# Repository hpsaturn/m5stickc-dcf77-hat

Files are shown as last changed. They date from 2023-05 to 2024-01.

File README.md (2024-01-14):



# M5StickC DCF77 HAT

Basic hat implementation of a DCF77 receiver on a M5StickC-Plus or compatible ESP32 devices. This firmware uses an [improvement of Arduino-DCF77 library](https://github.com/hpsaturn/Arduino-DCF77), using an event callback to improve the GUI and signal representation.

<table>
	<tr>
		<td>
			Don't forget to star ⭐ this repository
		</td>
	</tr>
</table>

## Device

The current firmware was tested on 77.5KHZ single frequency device. It is the 4 pins version and it was bought in [Aliexpress](https://www.aliexpress.com/item/1005005254051736.html).

## Wiring

| M5StickC pin | DCF77 pin | Description |
|:----:|:----:|:---|
| 0 | P | PON: Enable/Disable |
| 26 | T | Interrupt pin or data |
| 3.3v | VDD | Positive (3.3v) |
| GND  | GND | Ground / unlabeled pin |

(see the photos in [Thingiverse](https://www.thingiverse.com/thing:6033436))

## Usage

**Some tips:**  

- [x] Check the right device. Some devices has different frequencies for each country.
- [x] Try to leave the device from away any radio or wireless interference or noise. The radio is very susceptible to noise.
- [x] In indoors it works, but is possible that in some builds doesn't. Try in outdoors first.
- [x] The position of the device for me was important, in horizontal is possible that it works better

**Buttons:**

- Left button: Power ON/Off
- M5 Button: Backlight or brightness toggle
- Right button: Unimplementened  

## Installation

Please install first [PlatformIO](http://platformio.org/) open source ecosystem for IoT development compatible with **Arduino** IDE and its command line tools (Windows, MacOs and Linux). Also, you may need to install [git](http://git-scm.com/) in your system.

For the **default** board, the `M5StickCPlus`, only clone this and upload firmware via USB cable with a simple command:

`pio run --target upload`

or import the project in VSCode and build and run it.

## Box

Is a basic box - hat for these devices, for example M5StickC or M5StickC-Plus, also should be work in M5CoreInk device.

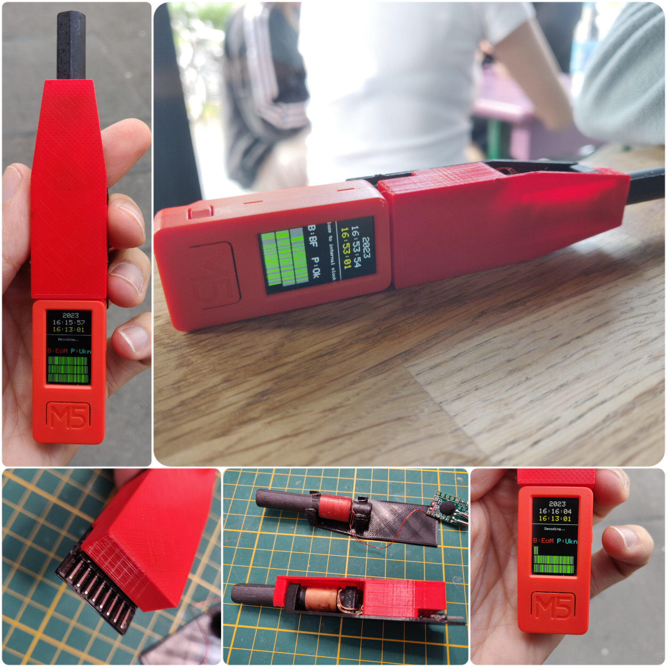
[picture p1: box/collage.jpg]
Box DCF77 M5StickCPlus Hat (https://youtu.be/C50qMhYiE60)


**Files:**  

DCF77 box base  
DCF77 box lid  

Also in [Thingiverse](https://www.thingiverse.com/thing:6033436).  

---

## Thanks to

@felmue to fix a sporadical crash.  
@jcomas for the help and docs on https://t.me/esp_es  
The old [DCF77 library](https://github.com/thijse/Arduino-DCF77)  
The [Seiko documentation](https://www.seikowatches.com/instructions/html/SEIKO_8B92_EN/CWVVSYxxhbpilh)

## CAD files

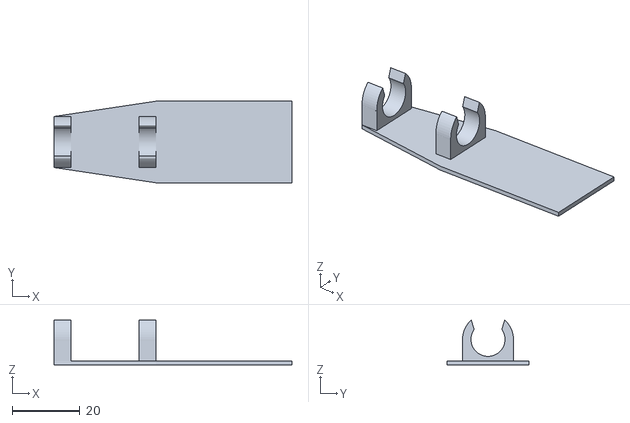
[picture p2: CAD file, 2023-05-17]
box/dfc77_holder_vertical.stl
70.0 x 24.0 x 13.2

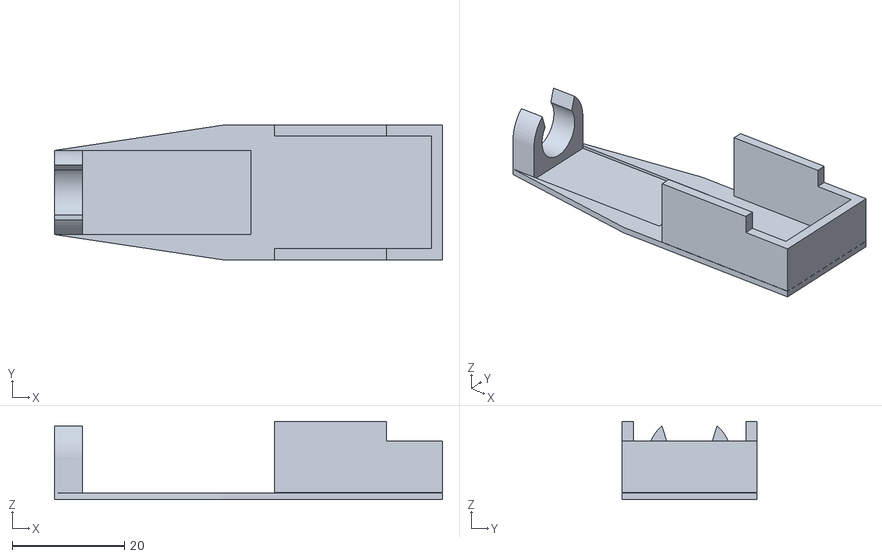
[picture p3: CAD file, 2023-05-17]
box/dfc77_holder_vertical_lid.stl
69.2 x 24.0 x 14.0

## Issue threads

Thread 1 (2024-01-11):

frequent crashes

felmue, 2024-01-11:
Hello there,

first of all, thank you very much for this repository.

I run the code on an M5StickCPlus and while it works ok the program from time to time crashes. Is that something you've encountered as well? Just curious.

I think it might have to do with the callback functions which are called from within the interrupt and on the ESP32 there are some restrictions regarding what's allowed in an interrupt and what not. I already removed all `Serial.print()` statements, but maybe writing to the screen is also problematic.

BTW: when I disable the callbacks I don't see any crashes anymore.

Thanks
Felix

hpsaturn, 2024-01-13:
Thanks for the feedback and comments. And yes, I noticed too that it had some concurrency issues maybe. But in this moment I did some test but I not founded the fix to the problem, and after that I used my only M5StickCPlus in other development, then I forget it. But if you catch the fix to the problem, please don't forget make a pull request here. Thanks in advance :D

felmue, 2024-01-14:
Hello @hpsaturn

[PR](https://github.com/hpsaturn/m5stickc-dcf77-hat/pull/2) to fix crash added.

Thanks
Felix

hpsaturn, 2024-01-14:
Thanks! I'm going to merge it to devel for now, to perform a long test in the device. But I seen that everything are ok in the code review.

hpsaturn, 2024-01-14:
resolved on #2 and added in the last release:
https://github.com/hpsaturn/m5stickc-dcf77-hat/releases/tag/v0.1.3

Closed 2024-01-14.

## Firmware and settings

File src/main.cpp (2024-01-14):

#include <Arduino.h>
#include <DCF77.h>

#include "gui.h"

#define DCF77_PON_PIN 0   // DCF77 operation pin
#define DCF_PIN 26        // Connection pin to DCF 77 device
#define DCF_INTERRUPT 26  // Interrupt number associated with pin

#define M5STICKCPLUS_LED GPIO_NUM_10

DCF77 DCF = DCF77(DCF_PIN, DCF_INTERRUPT, true);

#define BRIGHT_SIZE 5
int backlight[BRIGHT_SIZE] = {5, 15, 30, 50, 70};
int brightness = 1;  // MAX brightness is BRIGHT_SIZE

int signalpos = SIGNMARG;  // signal bar position
int bandposy = SIGNPOSY;   // signals band position

volatile unsigned char mySignal = 0;
volatile uint64_t myTimerInterval = 0;

typedef enum {
  BUFFER_MSG_NONE,
  BUFFER_MSG_EOM,
  BUFFER_MSG_BF,
} buffer_msg_t;

volatile buffer_msg_t myOnBufferMsg = BUFFER_MSG_NONE;

typedef enum {
  TIME_UPDATE_MSG_NONE,
  TIME_UPDATE_MSG_CLOSE_TO_INTERNAL_CLOCK,
  TIME_UPDATE_MSG_TIME_LAG_CONSISTENT,
  TIME_UPDATE_MSG_TIME_LAG_INCONSISTENT,
} time_update_t;

volatile time_update_t myOnTimeUpdateMsg = TIME_UPDATE_MSG_NONE;

typedef enum {
  PARITY_ERROR_NONE,
  PARITY_ERROR_ERR,
} parity_error_t;

volatile parity_error_t myOnParityError = PARITY_ERROR_NONE;

uint64_t millis64() {
  return (esp_timer_get_time() / 1000ULL);
}

class mDCF77EventsCallback : public DCF77EventsCallback {
  void onSignal(unsigned char signal) {
    mySignal = signal;
    digitalWrite(M5STICKCPLUS_LED, LOW);
    if (signal == 0)
      myTimerInterval = millis64() + 100;
    else
      myTimerInterval = millis64() + 200;
  };

  void onBufferMsg(const char* msg) {
    if (String(msg) == "EoM")
      myOnBufferMsg = BUFFER_MSG_EOM;
    else if (String(msg) == "BF")
      myOnBufferMsg = BUFFER_MSG_BF;
  };

  void onTimeUpdateMsg(const char* msg) {
    if (String(msg) == "Close to internal clock")
      myOnTimeUpdateMsg = TIME_UPDATE_MSG_CLOSE_TO_INTERNAL_CLOCK;
    else if (String(msg) == "Time lag consistent")
      myOnTimeUpdateMsg = TIME_UPDATE_MSG_TIME_LAG_CONSISTENT;
    else if (String(msg) == "Time lag inconsistent")
      myOnTimeUpdateMsg = TIME_UPDATE_MSG_TIME_LAG_INCONSISTENT;
  };

  void onParityError() {
    myOnParityError = PARITY_ERROR_ERR;
  };
};

void dcfLoop() {
  static uint_fast64_t tts = 0;  // timestamp for GUI refresh
  if (millis64() - tts > 1000) {
    tts = millis64();
    time_t DCFtime = DCF.getTime();  // Check if new DCF77 time is available
    if (DCFtime != 0) {
      Serial.printf("\rTime is updated: ");
      setTime(DCFtime);
      printLastTimeUpdate();
      serialPrintClock();
    }
    printYear();
    printTime();
  }
}

void cbLoop() {
  if ((myTimerInterval > 0) && (millis64() > myTimerInterval)) {
    myTimerInterval = 0;
    digitalWrite(M5STICKCPLUS_LED, HIGH);

    if (mySignal == 0)
      M5.Lcd.fillRect(signalpos, bandposy, 2, SIGNHIGH, TFT_DARKGREY);
    else
      M5.Lcd.fillRect(signalpos, bandposy, 2, SIGNHIGH, TFT_GREEN);
    signalpos = signalpos + 2;
  }

  if (myOnBufferMsg != BUFFER_MSG_NONE) {
    signalpos = SIGNMARG;
    M5.Lcd.setTextSize(2);
    switch (myOnBufferMsg) {
      case BUFFER_MSG_EOM:
        printBuffer("EoM", TFT_RED);
        printParity("Ukn", TFT_CYAN);
        printStatus("Decoding..");
        bandposy = SIGNPOSY;
        break;
      case BUFFER_MSG_BF:
        printBuffer("BF", TFT_WHITE);
        printParity("Ok", TFT_WHITE);
        bandposy = bandposy + SIGNHIGH + 3;
        if (bandposy >= (SIGNPOSY + (SIGNHIGH + 3) * MAXBANDS)) {
          bandposy = SIGNPOSY;
        }
        break;
    }
    M5.Lcd.fillRect(SIGNMARG, bandposy, 121, SIGNHIGH, BLACK);
    myOnBufferMsg = BUFFER_MSG_NONE;
  }

  if (myOnTimeUpdateMsg != TIME_UPDATE_MSG_NONE) {
    switch (myOnTimeUpdateMsg) {
      case TIME_UPDATE_MSG_CLOSE_TO_INTERNAL_CLOCK:
        printStatus("Close to internal clock");
        break;
      case TIME_UPDATE_MSG_TIME_LAG_CONSISTENT:
        printStatus("Time lag consistent");
        break;
      case TIME_UPDATE_MSG_TIME_LAG_INCONSISTENT:
        printStatus("Time lag inconsistent");
        break;
      default:
        printStatus("Unknown time update msg");
        break;
    }
    myOnTimeUpdateMsg = TIME_UPDATE_MSG_NONE;
  }

  if (myOnParityError == PARITY_ERROR_ERR) {
    updateField(TFT_WIDTH - 60, INFOPOSY + DATEHIGH + 7, 60, DATEHIGH, TFT_CYAN);
    M5.Lcd.printf("P:Err");
    myOnParityError = PARITY_ERROR_NONE;
  }
}

void setup() {
  Serial.begin(115200);
  M5.begin();
  pinMode(M5STICKCPLUS_LED, OUTPUT);
  digitalWrite(M5STICKCPLUS_LED, HIGH);
  M5.Lcd.fillScreen(BLACK);
  M5.Lcd.setTextColor(WHITE);
  M5.Lcd.drawLine(0, DATEPOSY + DATEHIGH * 3 + 2, TFT_WHITE, DATEPOSY + DATEHIGH * 2 + 2, TFT_WHITE);

  M5.Axp.ScreenBreath(backlight[brightness]);

  delay(200);
  Serial.flush();

  // Configure DCF77
  // (LOW = Normal operation, HIGH = standby)
  pinMode(DCF77_PON_PIN, OUTPUT);
  digitalWrite(DCF77_PON_PIN, LOW);

  DCF.setCallBack(new mDCF77EventsCallback());
  DCF.Start();
  Serial.println("Waiting for DCF77 time ... ");
  Serial.println("It will take at least 2 minutes until a first update can be processed.");
  delay(100);
  printStatus("It will take at least 2 minutes");
}

void buttonLoop() {
  M5.update();
  if (M5.BtnA.wasReleased()) {  // If the button A is pressed.
    if (brightness++ >= BRIGHT_SIZE - 1) brightness = 0;
    M5.Axp.ScreenBreath(backlight[brightness]);
  }
}

void loop() {
  buttonLoop();
  dcfLoop();
  cbLoop();
  delay(80);
}

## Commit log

2023-05-17 initial version working on a receiver of 4 pins
    [dfc77_holder_vertical.stl, dfc77_holder_vertical_lid.stl]
2023-05-17 added library fork target and fixed brightness issue
    [main.cpp]
2023-05-18 fixed core panic issue. First version with signal band
    [main.cpp]
2023-05-18 added callback for DCFTime (fixed concurrency issues)
    [main.cpp]
2023-05-18 refactor of GUI methods. Print status with split feature
2023-05-19 fixed concurrency issue (time update and callback crash)
    [main.cpp]
2023-05-19 restored time print on serial. Added youtube link
2024-01-14 Fix crash
    No console output and no display updates from within interrupt.
    [main.cpp]
2024-01-14 fixed framework to 4.4.0 (more stable for esp32)
